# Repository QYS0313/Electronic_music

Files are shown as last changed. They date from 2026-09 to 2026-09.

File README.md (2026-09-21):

# Electronic Music — STM32 电子琴

基于 STM32G431CBT6 的便携式电子琴。固件内置一个 4 声部 FM 合成器，19 个实体按键，通过片上 12 位 DAC 输出音频。仓库同时包含固件、PCB 工程和外壳 3D 模型，是一套完整的开源硬件项目。

## 功能特性

- **4 声部复音**：可同时按下 4 个键，超出时自动替换最早按下的声部
- **12 种音色**：钢琴、木琴、笛音等，通过专用按键循环切换
- **FM 合成 + ADSR 包络**：每种音色有独立的起音/衰减/延音/释放参数和 FM 调制参数
- **48 kHz 采样率**：由 TIM6 定时中断驱动，DDS 相位累加查表生成波形
- **18 个音键**：覆盖 C3 起的音域，不同音色有各自的基准音高偏移
- **纯硬件按键扫描**：GPIO 上拉输入，5 ms 轮询去抖

## 仓库结构

```
Electronic_music/
├── firmware/              STM32 固件（STM32CubeMX + CMake 工程）
│   ├── Core/              应用代码，合成器实现在 Core/Src/main.c
│   ├── Drivers/           STM32G4 HAL 库与 CMSIS
│   ├── Electronic_music.ioc   CubeMX 配置文件
│   └── CMakeLists.txt
├── hardware/              PCB 设计
│   ├── Electronic_music.epro2       嘉立创 EDA 专业版工程（原理图 + PCB）
│   └── Electronic_music_Gerber.zip  Gerber 生产文件，可直接用于打板
└── mechanical/            外壳 3D 模型
    ├── solidworks/        SolidWorks 源文件（4 个零件 + 总装配体）
    └── stl/               导出的 STL，可直接 3D 打印
```

## 硬件

| 项目 | 说明 |
|---|---|
| 主控 | STM32G431CBT6，Cortex-M4F，170 MHz |
| 音频输出 | DAC1 通道 1（PA4），12 位 |
| 采样定时 | TIM6，170 MHz / 17 / 208 ≈ 48 kHz |
| 按键 | 19 个 GPIO 输入（内部上拉，按下接地） |
| 调试接口 | SWD（PA13 / PA14） |

按键与引脚的对应关系见 `firmware/Core/Src/main.c` 中的 `keymap` 数组，第 18 号键为音色切换键。

DAC 输出为 0～3.3 V 的直流偏置信号，需经过外部低通滤波和功放后驱动扬声器，电路见 PCB 工程。

## 固件编译

### 环境要求

- [Arm GNU Toolchain](https://developer.arm.com/downloads/-/arm-gnu-toolchain-downloads)（arm-none-eabi-gcc）
- CMake 3.22 以上
- Ninja
- STM32CubeMX（仅在需要修改外设配置时）

### 编译步骤

```bash
cd firmware
cmake --preset Debug
cmake --build --preset Debug
```

生成的 `Electronic_music.elf` 位于 `firmware/build/Debug/`，可用 STM32CubeProgrammer 或 OpenOCD 通过 SWD 烧录。

也可以直接用 VS Code 打开 `firmware` 文件夹，安装 STM32 VS Code Extension 后一键编译下载。

## 合成器原理简述

1. **音高**：启动时预计算 48 个半音（C3～B6）的 32 位相位增量，按键时查表得到载波频率。
2. **FM 调制**：每个声部有一个调制器相位累加器，调制深度随时间按音色参数指数衰减，形成不同的音色质感。
3. **ADSR 包络**：每约 0.5 ms 更新一次，按音色参数控制音量变化。
4. **混音输出**：4 个声部叠加后乘以增益、限幅，映射到 0～4095 写入 DAC。

## 制作

1. 用 `hardware/Electronic_music_Gerber.zip` 打板并焊接元件
2. 3D 打印 `mechanical/stl/` 下的全部零件
3. 编译烧录固件
4. 组装

## 许可

代码部分基于 STMicroelectronics HAL 库，遵循其原有许可。其余部分由作者保留权利，欢迎学习交流。

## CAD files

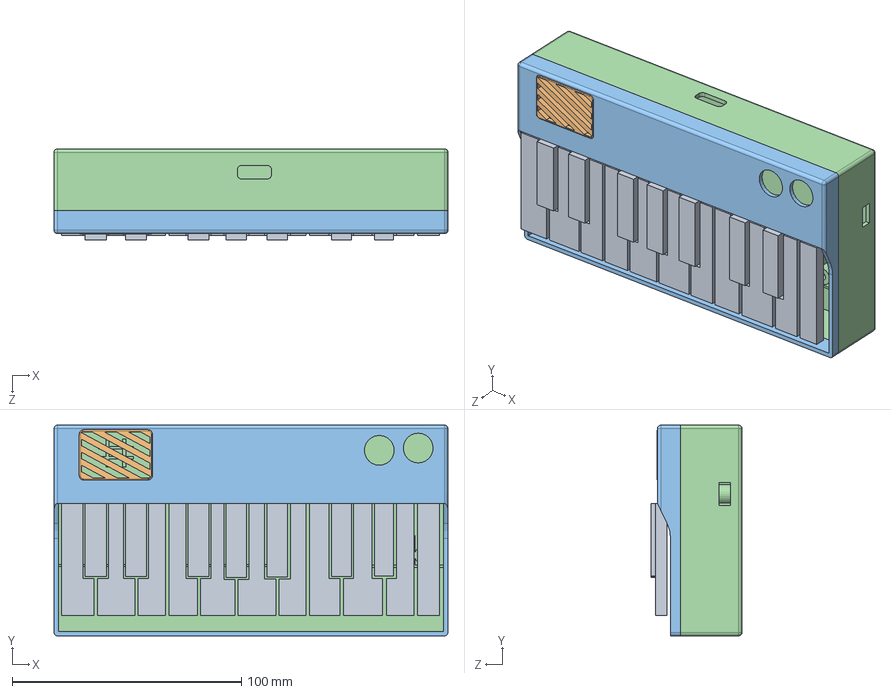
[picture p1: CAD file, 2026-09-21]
mechanical/solidworks/电子琴总.SLDASM
172.0 x 92.0 x 39.9 mm
电子琴1
电子琴2
电子琴3
电子琴keyboard

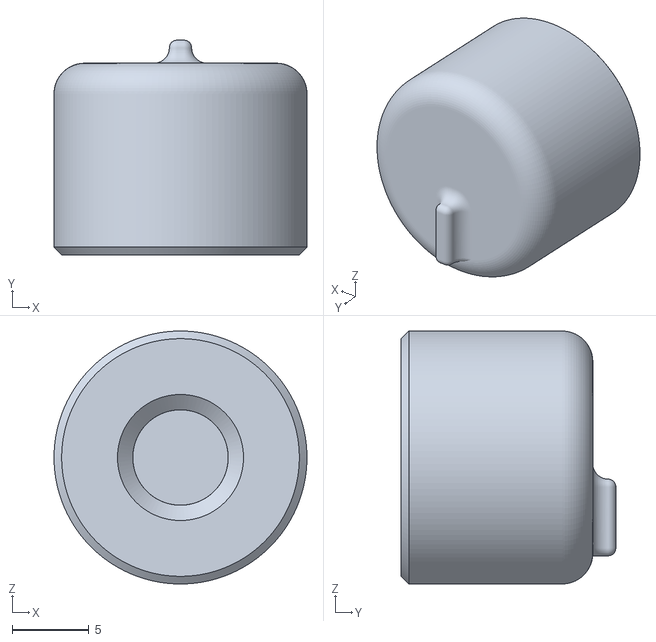
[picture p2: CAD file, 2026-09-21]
mechanical/stl/knob.stl
16.5 x 14.0 x 16.5

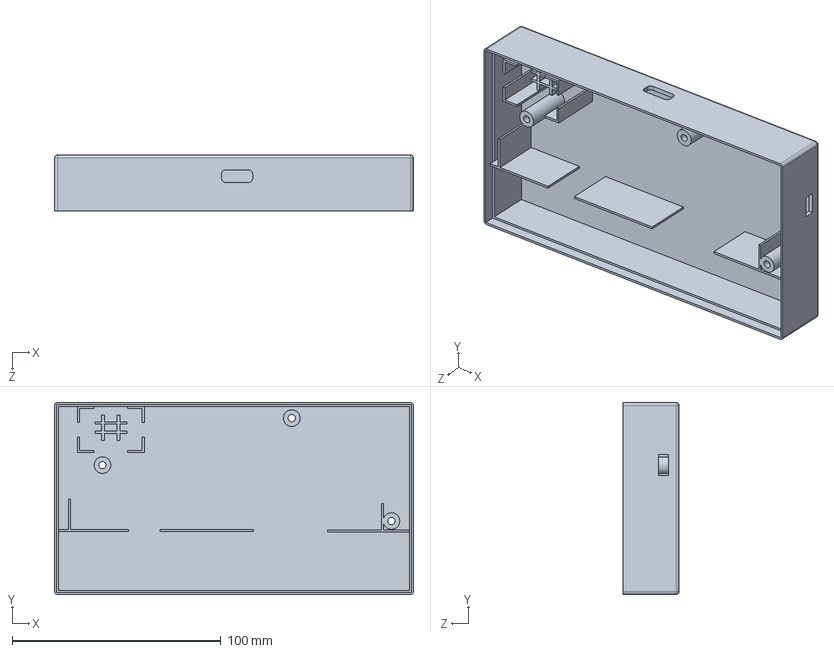
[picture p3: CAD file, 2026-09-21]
mechanical/solidworks/电子琴1.SLDPRT
172.0 x 92.0 x 27.0 mm

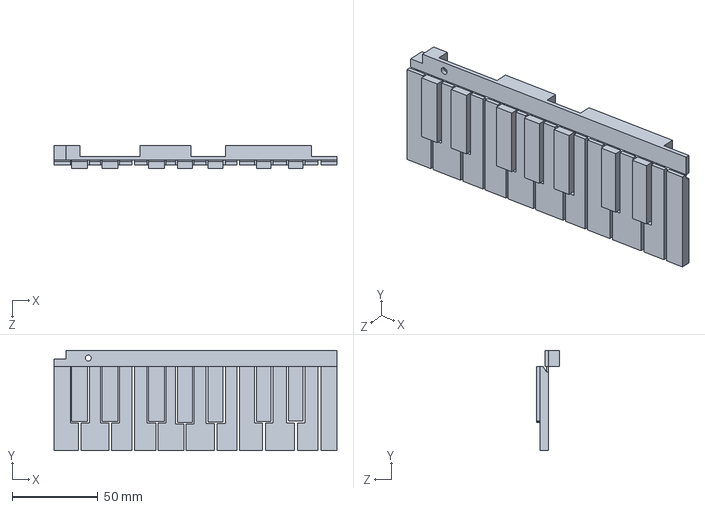
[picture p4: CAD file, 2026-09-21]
mechanical/solidworks/电子琴keyboard.SLDPRT
165.0 x 58.5 x 13.5 mm

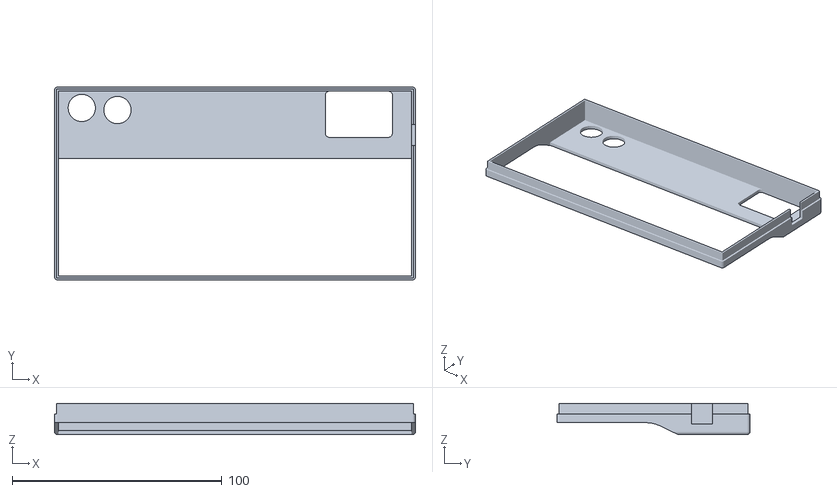
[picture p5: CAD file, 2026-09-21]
mechanical/stl/电子琴2_1.STL
172.0 x 92.0 x 15.0

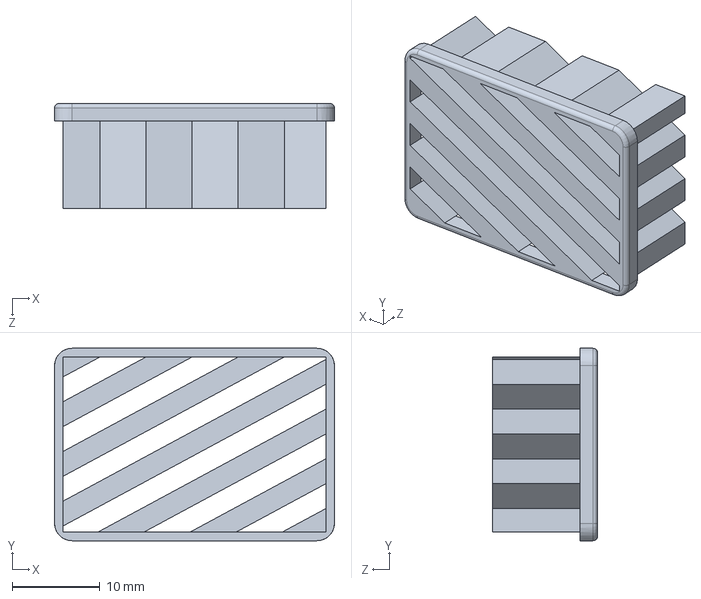
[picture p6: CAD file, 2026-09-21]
mechanical/solidworks/电子琴3.SLDPRT
32.0 x 22.0 x 12.0 mm

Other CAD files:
mechanical/stl/电子琴1_1.STL
mechanical/solidworks/电子琴2.SLDPRT
mechanical/stl/电子琴3.STL
mechanical/stl/电子琴keyboard.STL

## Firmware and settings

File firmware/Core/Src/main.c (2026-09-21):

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
/* Includes ------------------------------------------------------------------*/
#include "main.h"
#include "dac.h"
#include "stm32g4xx_hal.h"
#include "tim.h"
#include "gpio.h"

/* USER CODE BEGIN Includes */
#include "math.h"
#include <string.h>
#include <stdint.h>
#include <stdbool.h>
/* USER CODE END Includes */

/* USER CODE BEGIN PD */

//合成器参数
// 乐器定义
#define NINSTR 12// 定义乐器数量为12种：钢琴、木琴、笛音等
// 每种乐器的音量值
static const uint16_t ldness[NINSTR] =
  {64,64,64,64,64,64,64,64,64,64,64,64};
// 每种乐器的基准音高
static const uint8_t pitch0[NINSTR] =
  {12,12,12,12,24,24,0,12,24,12,12,24};
// ADSR 包络的起音参数
static const uint16_t ADSR_a[NINSTR] =
  {4096,8192,8192,8192,4096,512,512,8192,128,128,256,256};
// ADSR 包络的衰减参数
static const uint16_t ADSR_d[NINSTR] =
  {8,32,16,16,8,16,16,8,16,16,64,32};
// ADSR 包络的延音参数
static const uint16_t ADSR_s[NINSTR] =
  {0,0,0,0,0,0,0,0,240,240,192,192};
// ADSR 包络的释放参数
static const uint16_t ADSR_r[NINSTR] =
  {64,128,32,32,16,32,32,32,32,32,64,64};
// 每种乐器的 FM 调制频率增量，与音高相关
static const uint16_t FM_inc_tab[NINSTR] =
  {256,512,768,400,200,96,528,244,256,128,64,160};
// FM 调制幅度起始值
static const uint16_t FM_a1_tab[NINSTR] =
  {128,512,512,1024,512,0,1024,2048,256,256,384,256};
// FM 调制幅度结束值
static const uint16_t FM_a2_tab[NINSTR] =
  {64,0,128,128,128,512,768,512,128,128,256,128};
// FM 衰减参数
static const uint16_t FM_dec_tab[NINSTR] =
  {64,128,128,128,32,128,128,128,128,128,64,64};

//键定义
#define KEY_NOKEY 255// 无按键按下
#define KEY_INSTR 254// 乐器选择按键
typedef struct { GPIO_TypeDef* port; uint16_t pin; } KeyPin;
KeyPin keymap[19] = {
  /* fill with your real pins */
  {GPIOA, GPIO_PIN_12}, /* key 0: e.g. C5 -> replace with your pin */
  {GPIOB, GPIO_PIN_4},
  {GPIOB, GPIO_PIN_6},
  {GPIOB, GPIO_PIN_7},
  {GPIOB, GPIO_PIN_9},
  {GPIOB, GPIO_PIN_11},
  {GPIOB, GPIO_PIN_1},
  {GPIOB, GPIO_PIN_0},
  {GPIOA, GPIO_PIN_2},
  {GPIOC, GPIO_PIN_15},
  {GPIOC, GPIO_PIN_13},
  {GPIOB, GPIO_PIN_3},
  {GPIOB, GPIO_PIN_5},
  {GPIOA, GPIO_PIN_15},
  {GPIOB, GPIO_PIN_10},
  {GPIOB, GPIO_PIN_2},
  {GPIOA, GPIO_PIN_7},
  {GPIOA, GPIO_PIN_1},
  {GPIOB, GPIO_PIN_13}
};

//DDS / 波表
#define SINE_LEN 256
static int16_t sine_table[SINE_LEN];

//相位累加器宽度
typedef uint32_t phase_t;

//采样率（与 TIM6 设置匹配）
#define SAMPLE_RATE 48082UL /* ~170MHz/(17*208) */

//48 个半音的预计算音调增量 （C3 ..B6）
#define TONE_COUNT 48
static uint32_t tone_inc[TONE_COUNT]; // 每个半音的每个样本的相位增量

//合成器运行时状态 
#define NCH 4
static phase_t phase_acc[NCH];
static uint32_t inc_base[NCH];
static uint8_t amp_base[NCH];
static uint32_t envADSR[NCH];
static uint8_t iADSR[NCH];
static uint32_t FMphase[NCH];
static int32_t FMinc_base[NCH];
static int32_t FMa0[NCH];
static int32_t FMda[NCH];
static uint32_t FMexp[NCH];
static uint16_t FMdec[NCH];
static uint8_t keych[NCH];
static uint32_t tch[NCH];

static volatile uint8_t current_instr = 0;

//键态简单轮询
#define KEYCOUNT 19
static uint8_t lastKeyStates[KEYCOUNT];






/* USER CODE END PD */


void SystemClock_Config(void);
/* USER CODE BEGIN 0 */

//实用程序：计算半音索引 i 的频率，其中索引 0 = C3 （MIDI 48）
static double midi_freq(int midi_note) {
  return 440.0 * pow(2.0, (midi_note - 69) / 12.0);
}

/* TIM6 中断回调 - 合成器的核心 （48kHz） */
void HAL_TIM_PeriodElapsedCallback(TIM_HandleTypeDef *htim)
{
  if (htim->Instance == TIM6) {
    /* ---更新 FM exp 衰减（矢量化）--- */
    for (int ch=0; ch<NCH; ch++){
      /* FMexp 衰减：近似原始行为 */
      FMphase[ch] += FMinc_base[ch];
      phase_acc[ch] += inc_base[ch];
    }


    static uint16_t env_counter = 0;
    const uint16_t ENV_DECIM = 23;
    if (++env_counter >= ENV_DECIM){ 
      env_counter = 0;

      /* FMexp 衰减（慢） */
      for (int ch=0; ch<NCH; ch++){
        FMexp[ch] -= ( (uint64_t)FMexp[ch] * FMdec[ch]) >> 16;
      }


      /* --- ADSR 更新和信道时间计数器 --- */
      for (int ch=0; ch<NCH; ch++){
        switch (iADSR[ch]) {
          case 0: /* off */ break;
          case 1: /*攻击*/
            if ((0xFFFF - envADSR[ch]) <= ADSR_a[current_instr]) {
              envADSR[ch] = 0xFFFF;
              iADSR[ch] = 2;
            } else {
              envADSR[ch] += ADSR_a[current_instr];
            }
            break;
          case 2: /*衰变*/
            if (envADSR[ch] <= (uint32_t)(ADSR_s[current_instr] << 8) + ADSR_d[current_instr]) {
              envADSR[ch] = (ADSR_s[current_instr] << 8);
              iADSR[ch] = 3;
            } else {
              envADSR[ch] -= ADSR_d[current_instr];
            }
            break;
          case 3: /*维持*/ break;
          case 4: /*释放*/
            if (envADSR[ch] <= ADSR_r[current_instr]) {
              envADSR[ch] = 0;
              iADSR[ch] = 0;
              amp_base[ch]=0;
              keych[ch]=KEY_NOKEY;
            } else {
              envADSR[ch] -= ADSR_r[current_instr];
            }
            break;
        }
        tch[ch]++; /* time counter */
      }
    }
     

    /* --- 从 4 个声部计算混合样本 --- */
    int32_t mix = 0;
    for (int ch=0; ch<NCH; ch++){
      if (iADSR[ch] == 0) {
        /* voice off */
        continue;
      }
      /* 高级调频相位 */
      FMphase[ch] += FMinc_base[ch];
      /* 推进主相 */
      phase_acc[ch] += inc_base[ch];

      /* 采样 FM 调制器 */
      uint8_t fm_index = (uint8_t)(FMphase[ch] >> 24); /* top 8 bits */
      int32_t fm_val = sine_table[fm_index]; /* -128..127 */

      /* 调制相位偏移（小） */
      int32_t mod = (fm_val * (FMa0[ch] + ((int64_t)FMda[ch] * (int32_t)FMexp[ch] >> 16))) >> 8;
      /* 计算载波的最终相位索引 */
      uint8_t idx = (uint8_t)((phase_acc[ch] + (mod << 8)) >> 24); /* map to 0..255 */
      int32_t carrier = sine_table[idx]; /* -128..127 */

      /* 来自环境（envADSR 为 0..0xFFFF）和amp_base（体积）的幅度 */
      int32_t amp = ((int32_t)amp_base[ch] * (envADSR[ch] >> 8)) >> 8; /* 0..255 */
      int32_t voice = (carrier * amp) >> 8; /* approx -128..127 scaled */
      mix += voice;
    }

    /* 混合大约是 -512..512 也许;缩放到 DAC 范围 0..4095（12 位）*/
    int32_t out = mix; /* centered near 0 */
    /* --- 软件增益调整（尝试不同增益值） --- */
    const int GAIN = 4; /* 试 4, 6, 8 直到合适 */
    out = out * GAIN; /* 放大mix */
    /* 简单的夹紧和缩放 */
    if (out > 2047) out = 2047;
    if (out < -2048) out = -2048;
    uint16_t dacval = (uint16_t)((out + 2048) * 4095 / 4095); /* center to 0..4095 */
    /* 写入 DAC */
    HAL_DAC_SetValue(&hdac1, DAC_CHANNEL_1, DAC_ALIGN_12B_R, dacval);
  }
}

/* --- 简单的助手：在下一个可用频道---开始笔记 */
static void handle_key_pressed(uint8_t k) {
  if (k >= 19) return;
  /* 仪器选择（如果是特殊键） - 根据需要实施 */
  if (k == 18) { /* 前ample：键 18 作为仪表开关 */
    current_instr++;
    if (current_instr >= NINSTR) current_instr = 0;
    return;
  }

  /* 找到类似于 Arduino 逻辑的 nextch */
  int nextch = -1;
  for (int i=0;i<NCH;i++){
    if (iADSR[i]>0 && keych[i]==k) { nextch = i; break; }
  }
  if (nextch == -1) {
    for (int i=0;i<NCH;i++){
      if (iADSR[i]==0) { nextch = i; break; }
    }
  }
  if (nextch == -1) {
    /* 偷走最旧的 */
    nextch = 0;
    for (int i=1;i<NCH;i++) if (tch[i] > tch[nextch]) nextch = i;
  }

  /* 初始化语音 */
  phase_acc[nextch] = 0;
  amp_base[nextch] = ldness[current_instr];
  /* inc_base: use pitch0 + key mapping (assume key index maps directly to semitone offset) */
  /* in original code, tone_inc[pitch0[instr] + keypressed] */
  int semitoneIndex = (int)pitch0[current_instr] + (int)k; /* ensure in range */
  if (semitoneIndex < 0) semitoneIndex = 0;
  if (semitoneIndex >= TONE_COUNT) semitoneIndex = TONE_COUNT-1;
  inc_base[nextch] = tone_inc[semitoneIndex];
  envADSR[nextch]=0;
  iADSR[nextch] = 1; /* attack */
  FMphase[nextch] = 0;
  FMinc_base[nextch] = ((int64_t)inc_base[nextch] * FM_inc_tab[current_instr]) / 256;
  FMa0[nextch] = FM_a2_tab[current_instr];
  FMda[nextch] = (int32_t)FM_a1_tab[current_instr] - (int32_t)FM_a2_tab[current_instr];
  FMexp[nextch] = 0xFFFFFFFF;
  FMdec[nextch] = FM_dec_tab[current_instr];
  keych[nextch] = k;
  tch[nextch] = 0;
}

static void handle_key_released(uint8_t k) {
  for (int i=0;i<NCH;i++){
    if (keych[i] == k) {
      iADSR[i] = 4; /* release */
    }
  }
}

/* ---初始化助手 --- */
static void init_sine_table(void) {
  for (int i=0;i<SINE_LEN;i++){
    double v = sin(2.0*M_PI*(i+0.5)/ (double)SINE_LEN);
    sine_table[i] = (int16_t)(v * 127.0); /* -127..127 */
  }
}

/* 计算从 MIDI 48 （C3） 开始的 48 个半音的tone_inc表 */
static void init_tone_inc(void) {
  for (int i=0;i<TONE_COUNT;i++){
    int midi = 48 + i; /* C3 = MIDI 48 */
    double f = midi_freq(midi);
    /* 32 位相位累加器在 SAMPLE_RATE 处的相位增量 */
    uint32_t inc = (uint32_t)((f * (double)( (uint64_t)1 << 32 )) / (double)SAMPLE_RATE + 0.5);
    tone_inc[i] = inc;
  }
}

/* USER CODE END 0 */

/**
  * @brief  The application entry point.
  * @retval int
  */
int main(void)
{

  /* MCU Configuration--------------------------------------------------------*/

  /* Reset of all peripherals, Initializes the Flash interface and the Systick. */
  HAL_Init();

  /* Configure the system clock */
  SystemClock_Config();

  /* Initialize all configured peripherals */
  MX_GPIO_Init();
  MX_DAC1_Init();
  MX_TIM6_Init();
  /* USER CODE BEGIN 2 */

  //合成器初始化 
  init_sine_table();
  init_tone_inc();

   //初始化声音 
  for (int i=0;i<NCH;i++) {
    phase_acc[i]=0;
    inc_base[i]=0;
    amp_base[i]=0;
    envADSR[i]=0;
    iADSR[i]=0;
    FMphase[i]=0;
    FMexp[i]=0xFFFFFFFF;
    keych[i]=KEY_NOKEY;
    tch[i]=0;
  }

  /* 启动 DAC 输出 - 无触发器，我们通过 ISR 中的 HAL 写入 */
  HAL_DAC_Start(&hdac1, DAC_CHANNEL_1);
  HAL_DAC_SetValue(&hdac1, DAC_CHANNEL_1, DAC_ALIGN_12B_R, 2048);
  HAL_Delay(20);
  /* 启动 TIM6 中断（采样定时器） */
  HAL_TIM_Base_Start_IT(&htim6);


  /* USER CODE END 2 */

  /* Infinite loop */
  /* USER CODE BEGIN WHILE */
  while (1)
  {

    //每 ~5 毫秒进行一次简单的去抖动轮询
    HAL_Delay(5);
    for (int k=0;k<19;k++) {
      GPIO_PinState st = HAL_GPIO_ReadPin(keymap[k].port, keymap[k].pin);
      uint8_t pressed = (st == GPIO_PIN_RESET) ? 1 : 0; // assume pull-up
      if (pressed && !lastKeyStates[k]) {
        lastKeyStates[k]=1;
        handle_key_pressed((uint8_t)k);
      } else if (!pressed && lastKeyStates[k]) {
        lastKeyStates[k]=0;
        handle_key_released((uint8_t)k);
      }
    }
    /* 其他 UI：乐器更换可以是专用键或长按 */



    /* USER CODE END WHILE */

    /* USER CODE BEGIN 3 */
  }
  /* USER CODE END 3 */
}

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


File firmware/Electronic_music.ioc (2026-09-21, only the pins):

Mcu.UserName=STM32G431CBTx
PA1.Signal=GPIO_Input
PA12.Signal=GPIO_Input
PA13.Signal=SYS_JTMS-SWDIO
PA14.Signal=SYS_JTCK-SWCLK
PA15.Signal=GPIO_Input
PA2.Signal=GPIO_Input
PA4.Signal=COMP_DAC11_group
PA7.Signal=GPIO_Input
PB0.Signal=GPIO_Input
PB1.Signal=GPIO_Input
PB10.Signal=GPIO_Input
PB11.Signal=GPIO_Input
PB13.Signal=GPIO_Input
PB2.Signal=GPIO_Input
PB3.Signal=GPIO_Input
PB4.Signal=GPIO_Input
PB5.Signal=GPIO_Input
PB6.Signal=GPIO_Input
PB7.Signal=GPIO_Input
PB9.Signal=GPIO_Input
PC13.Signal=GPIO_Input
PC15-OSC32_OUT.Signal=GPIO_Input
PF0-OSC_IN.Signal=RCC_OSC_IN
PF1-OSC_OUT.Signal=RCC_OSC_OUT

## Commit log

2026-09-21 Initial commit: STM32G431 electronic piano
2026-09-21 Add PCB project (LCEDA Pro) and Gerber files
2026-09-21 Add SolidWorks models and STL exports
    [knob.stl, 电子琴1.SLDPRT, 电子琴1_1.STL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]
2026-09-21 Add unsorted STL files for review
    [buttom shell.stl, part1.stl, part2.stl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]
2026-09-21 Remove unsorted STL files
    [buttom shell.stl, part1.stl, part2.stl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]

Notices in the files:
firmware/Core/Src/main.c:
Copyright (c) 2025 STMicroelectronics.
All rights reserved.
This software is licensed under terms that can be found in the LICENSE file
